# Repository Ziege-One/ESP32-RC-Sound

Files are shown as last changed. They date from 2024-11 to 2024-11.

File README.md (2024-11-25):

# ESP32-RC-Sound for RC ships or cars

ESP32-RC-Sound first based on the work done by stelatoris and XTronical 

Github stelatoris: https://github.com/stelatoris/XTronical-I2S-Audio-with-SD

Website XTronical: https://www.xtronical.com/i2sprerelease/

and XTronical Youtube: https://www.youtube.com/channel/UCOjddcYTYcZBGhpBALhX4Kg

# Info:

under docs/ESP32 RC-Sound.pdf (German only)

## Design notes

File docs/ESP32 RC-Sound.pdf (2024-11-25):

Stand 15.09.2024 12:30

# ESP32 RC-Sound

## Der RC-Modellbauer

## alias Frank Verfürth

Software 0.36

Hardware 1.0

### 1 INHALT

### 2 EINLEITUNG

- Das ESP32 RC-Sound Modul ermöglicht die Simulation von Motorsounds und kann bis zu 8 verschiedene Sounds abspielen. Diese Sounddateien werden auf einer SD-Karte gespeichert. Das Modul bietet verschiedene Ansteuerungsmethoden für den Sound bzw. Motorsound, darunter SBUS, PWM, Pin to Ground, Einkanal aus dem ESP32 SBUS-Switch sowie eine Ebenen-Umschaltung zur Kanaloptimierung. Einstellungen werden über WLAN über ein geeignetes Endgerät vorgenommen.

## 3 ESP32 RC-SOUND

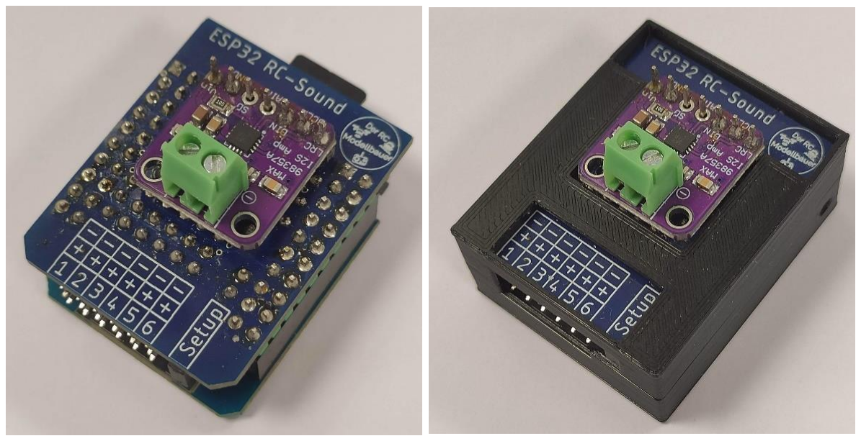
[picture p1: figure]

ESP32 RC-Sound Modul rechts ohne links mit Gehäuse aus dem 3D-Drucker

### 4 AUFBAU

### 4.1 BAUTEILE

- | ESP32 | ESP32-Mini
- Micro SD Modul
- MAX98357A I2S 3W Klasse-D-Verstärker

### 4.2 SPANNUNGSVERSORGUNG

Das Soundmodul wird über die Servostecker an Pin 1-6 mit Spannung versorgt. Die maximale Spannung beträgt 5,3V.

### 4.3 ANSCHLÜSSE

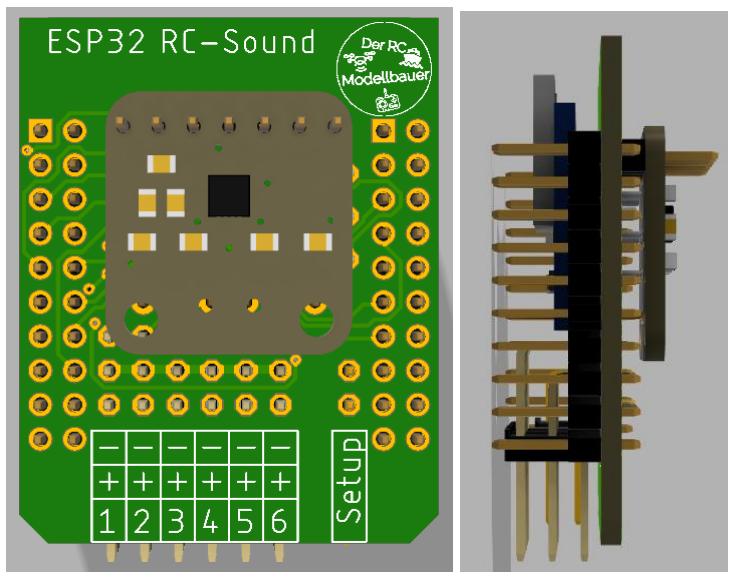
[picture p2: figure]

Pin1-6 (3Polig) sind freikonfigurierbare Eingänge siehe Verschaltung. Der „-„ Pin ist mit allen anderen „-„ Pins verbunden und mit GND der Schaltung verbunden. Die „+“ Pins sind ebenfalls alle untereinander verbunden, und dienen als Spannungsversorgung der Schaltung. Die „X“ Pins sind mit Eingängen des ESP32 verschaltet. Der Setup Pin (2Polig) dient zum aktivieren des Setupmodus und kann mit einem Jumper gesteckt werden.

### 4.3.1 SBUS

Wenn im ES32 RC-Sound Modul der SBUS verwendet werden wird dieser immer an PIN1 eingelesen.

### 4.3.2 PWM

Das PWM Signale wir je nach Einstellung am entsprechend PINx eingelesen. Ist in der Konfig „PWM PIN 2 xxx“ eingestellt wir an PIN2 ein PWM Signal eingelesen und entsprechend ausgewertet.

### 4.3.3 PIN to GND

Pin to GND ist immer nur ein Schaltbefehl. Um den entsprechend Pin zu aktivieren wird der „PINx“ mit den Pin „-„ verbunden. Dies kann über einen externen Relaiskontakt/ Mechanischer Schalter oder mit einem Negativ schaltenden Schaltmodul (ESP32 SBUS-Switch neg) erfolgen

### 5 BEDIENUNG

### 5.1 WLAN VERBINDEN

Das ESP32 RC-Sound Modul erstellt bei gesteckter Setupbrücke einen WLAN- Access Point mit folgenden Zugangsdaten

- SSID „ESP32 RC-Sound“
- Password „123456789“

Nach erfolgreicher Verbindung kann die Webseite über einen Webbrowser unter der Adresse

- http://192.168.1.1

aufgerufen werden.

## 6 SD-KARTE

### 6.1 WAVE FORMAT

- Abtastrate von 16.000 Hz ist empfehlenswert
- Mono
- Angepasste Lautstärke (Siehe Bild ca. 0,5 Amplitude)
- Software Empfehlung https://www.audacity.de/

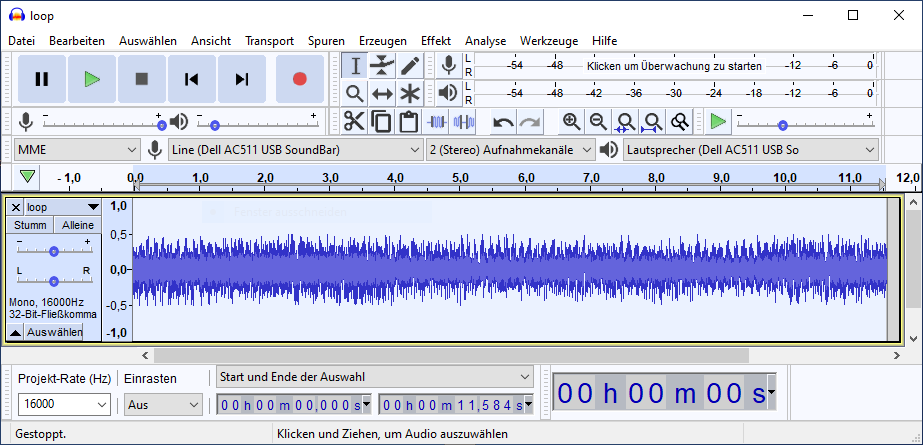
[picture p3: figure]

### 6.2 ORDNERSTRUKTUR

Die Dateien auf der SD-Karte sollten wie folgt strukturiert sein (Kleinschreibung beachten).

- | start.wav | -> | Motorstart Sound
- | loop.wav | -> | Motorgeräusch
- | shut.wav | -> | Motorabestell Sound
- | soundx.wav | -> | Sounds 1-8

### 7 WEBOBERFLÄCHE

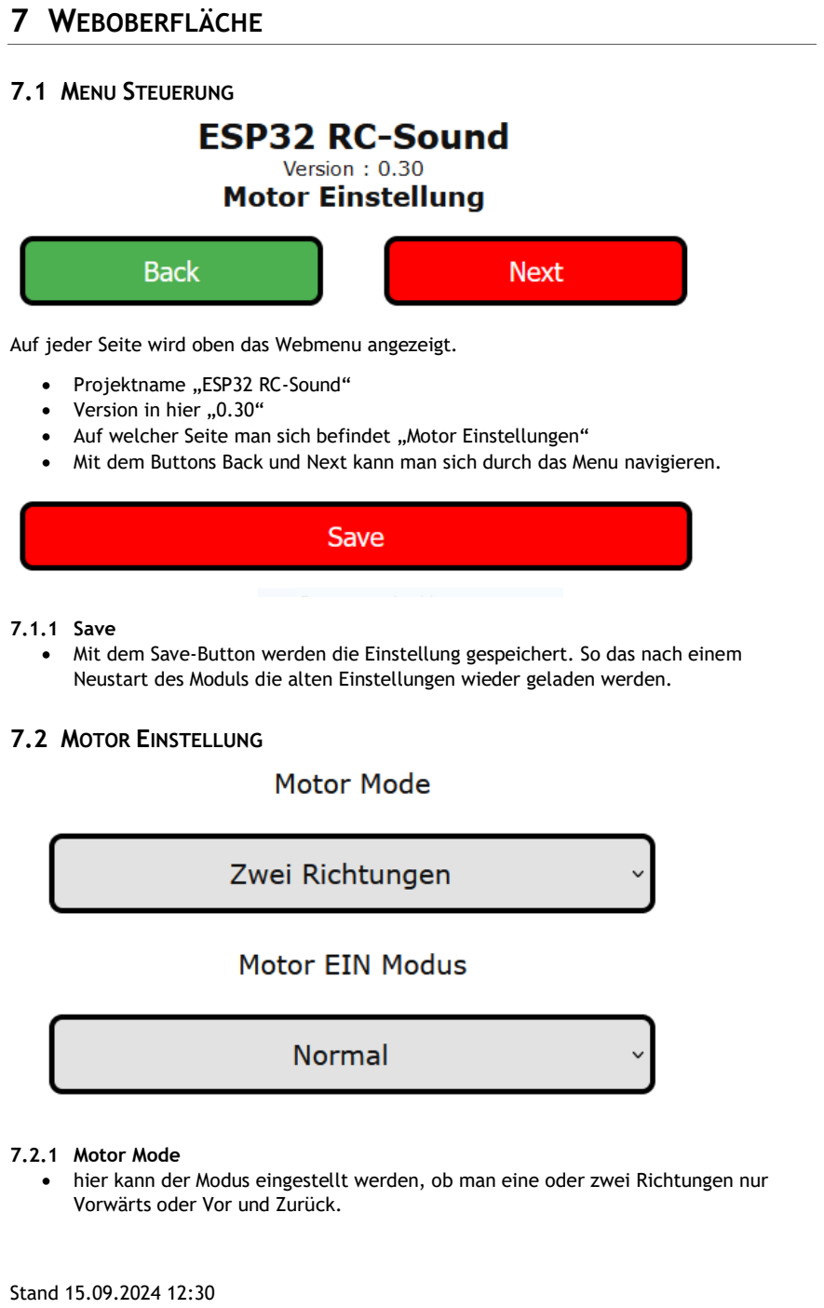
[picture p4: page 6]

### 7.1 MENU STEUERUNG

Auf jeder Seite wird oben das Webmenu angezeigt.

- Projektname „ESP32 RC-Sound“
- Version in hier „0.30“
- Auf welcher Seite man sich befindet „Motor Einstellungen“
- Mit dem Buttons Back und Next kann man sich durch das Menu navigieren.

### 7.1.1 Save

- Mit dem Save-Button werden die Einstellung gespeichert. So das nach einem Neustart des Moduls die alten Einstellungen wieder geladen werden.

### 7.2 MOTOR EINSTELLUNG

### 7.2.1 Motor Mode

- hier kann der Modus eingestellt werden, ob man eine oder zwei Richtungen nur Vorwärts oder Vor und Zurück.

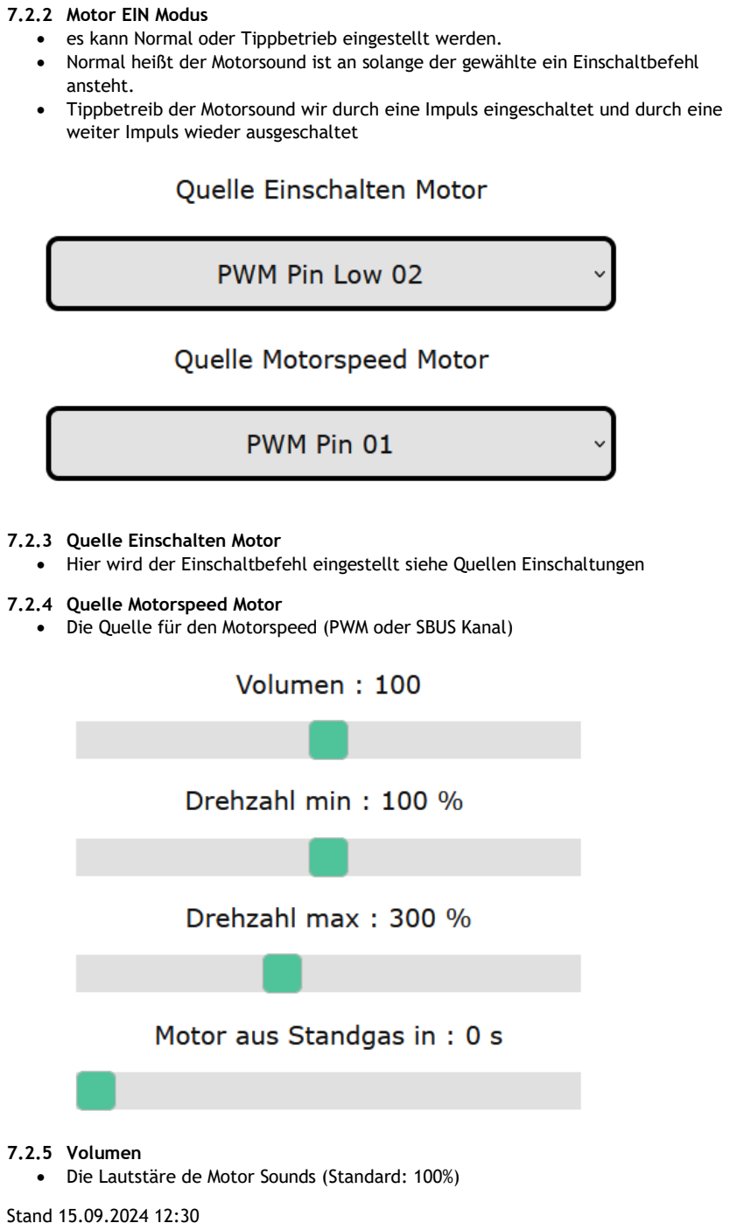
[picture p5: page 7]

### 7.2.2 Motor EIN Modus

- es kann Normal oder Tippbetrieb eingestellt werden.
- Normal heißt der Motorsound ist an solange der gewählte ein Einschaltbefehl ansteht.
- Tippbetreib der Motorsound wir durch eine Impuls eingeschaltet und durch eine weiter Impuls wieder ausgeschaltet

### 7.2.3 Quelle Einschalten Motor

- Hier wird der Einschaltbefehl eingestellt siehe Quellen Einschaltungen

### 7.2.4 Quelle Motorspeed Motor

- Die Quelle für den Motorspeed (PWM oder SBUS Kanal)

### 7.2.5 Volumen

- Die Lautstäre de Motor Sounds (Standard: 100%)

### 7.2.6 Drehzahl min

- Die Wiedergabegeschwindigkeit der loop.wav bei Standgas. 100% -> 1.0 fache Wiedergabegeschwindigkeit (Standard: 100%)

### 7.2.7 Drehzahl max

- Die Wiedergabegeschwindigkeit der loop.wav bei Vollgas. 300% -> 3.0 fache Wiedergabegeschwindigkeit (Standard: 300%)

### 7.2.8 Motor aus Standgas in

- Ist die Zeit die sich der Motor im Standgas befinden muss um automatisch abgeschaltet zu werden. 0 -> deaktiviert (Standard: 0s)

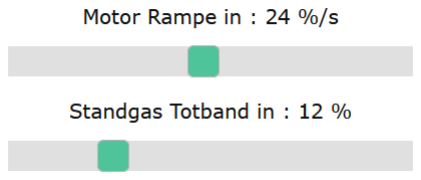
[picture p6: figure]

### 7.2.9 Motor Rampe in

- Ist die maximale Änderung der Geschwindigkeit des Motors in % pro Sekunde

### 7.2.10 Standgas Totband

- Wieviel % Gas gegeben werden muss bis der Motor aus dem Standgas kommt

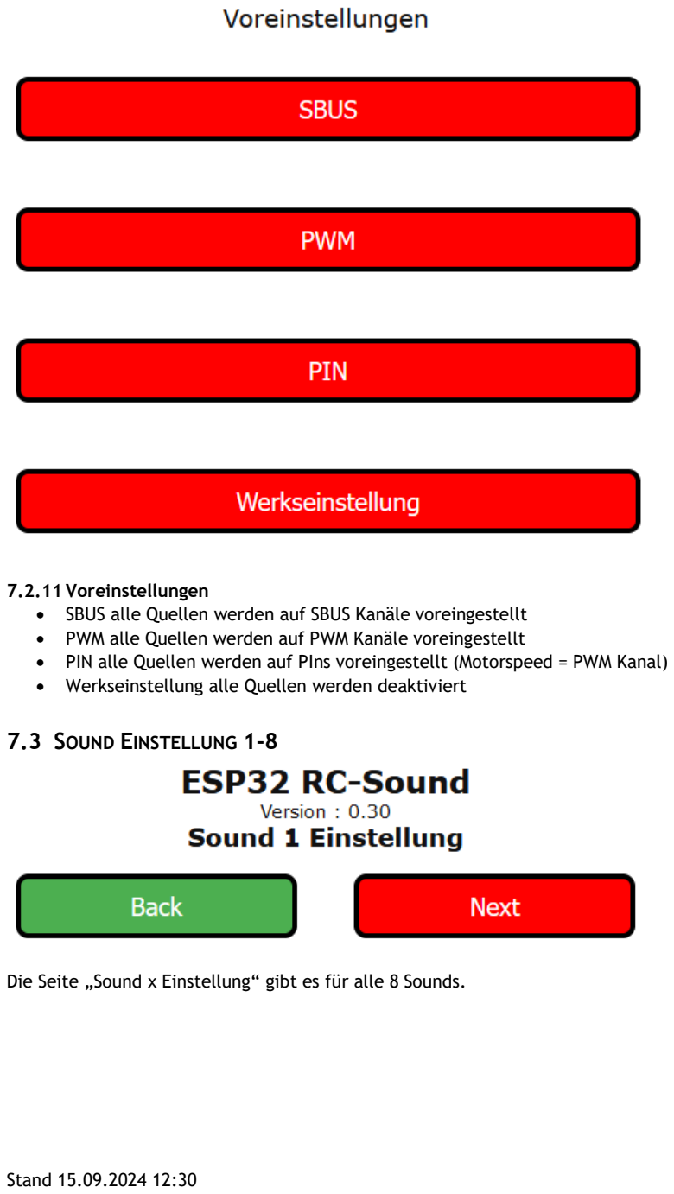
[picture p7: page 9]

### 7.2.11 Voreinstellungen

- SBUS alle Quellen werden auf SBUS Kanäle voreingestellt
- PWM alle Quellen werden auf PWM Kanäle voreingestellt
- PIN alle Quellen werden auf PIns voreingestellt (Motorspeed = PWM Kanal)
- Werkseinstellung alle Quellen werden deaktiviert

### 7.3 SOUND EINSTELLUNG 1-8

Die Seite „Sound x Einstellung“ gibt es für alle 8 Sounds.

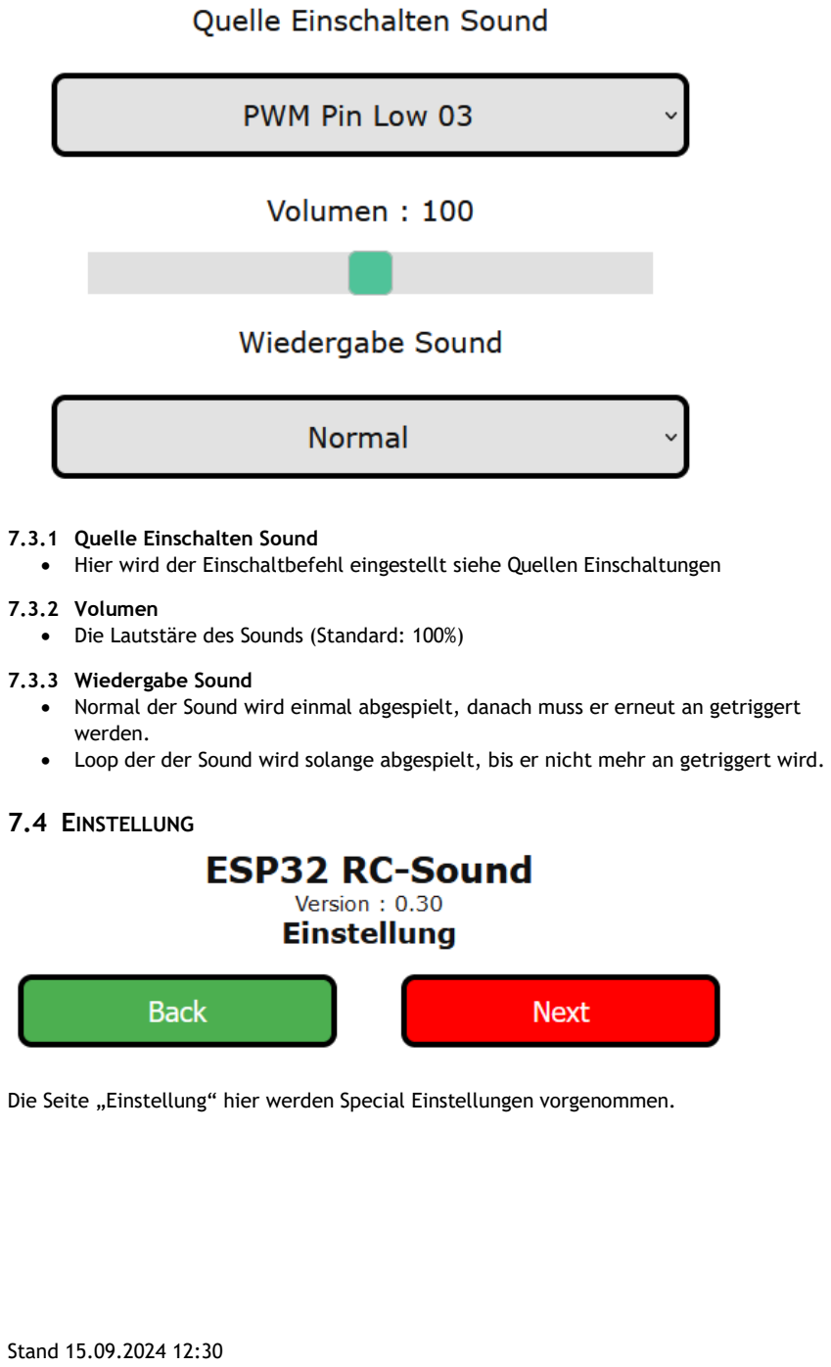
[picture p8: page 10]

### 7.3.1 Quelle Einschalten Sound

- Hier wird der Einschaltbefehl eingestellt siehe Quellen Einschaltungen

### 7.3.2 Volumen

- Die Lautstäre des Sounds (Standard: 100%)

### 7.3.3 Wiedergabe Sound

- Normal der Sound wird einmal abgespielt, danach muss er erneut an getriggert werden.
- Loop der der Sound wird solange abgespielt, bis er nicht mehr an getriggert wird.

### 7.4 EINSTELLUNG

Die Seite „Einstellung“ hier werden Special Einstellungen vorgenommen.

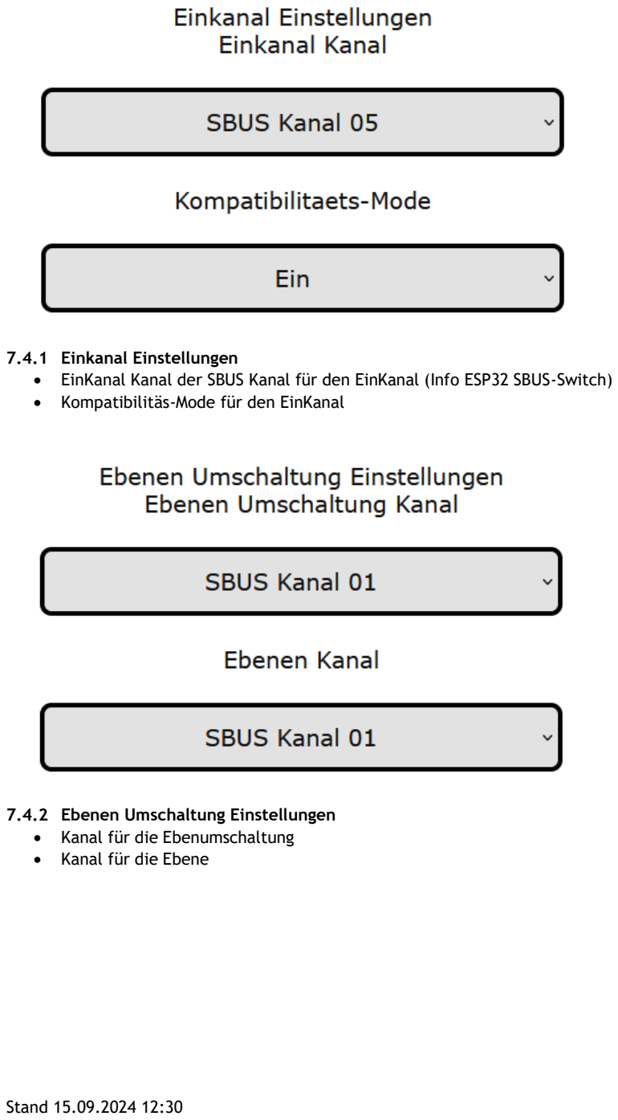
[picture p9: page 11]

### 7.4.1 Einkanal Einstellungen

- EinKanal Kanal der SBUS Kanal für den EinKanal (Info ESP32 SBUS-Switch)
- Kompatibilitäs-Mode für den EinKanal

### 7.4.2 Ebenen Umschaltung Einstellungen

- Kanal für die Ebenumschaltung
- Kanal für die Ebene

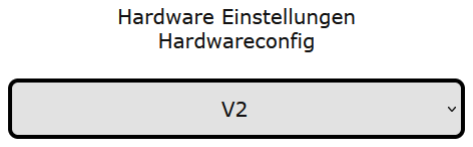
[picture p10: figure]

### 7.4.3 Hardware Einstellungen

- Hardwareconfig Platine V1 und Platine V2 siehe Anhang

### 7.5 DEBUG

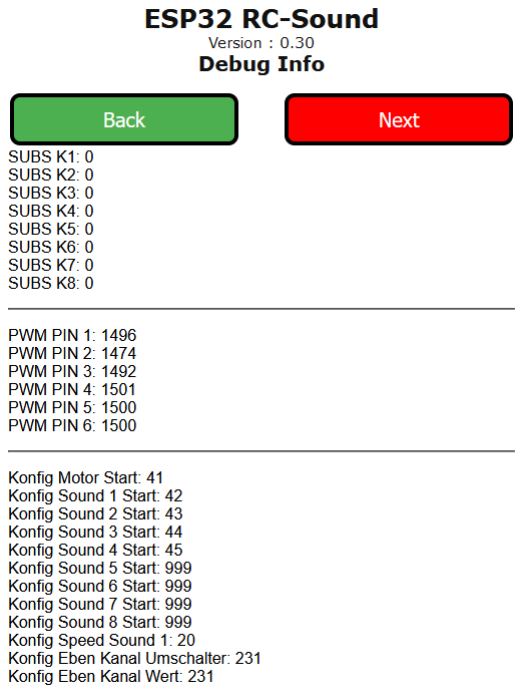
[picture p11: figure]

Hier werden Debug Informationen angezeigt

- SBUS K1-K8 die ersten 8 SBUS-Kanäle falls verwendet
- PWM PIN1-6 die PWM Werte der Pins 1-6 falls verwendet
- Anzeige der Konfig aus dem EEProm

### 8 ANHANG

### 8.1 MEHR INFORMATIONEN UND VIDEOS

- https://www.youtube.com/channel/UCkWFzuBmOhYu49MQkq89nMw

### 8.2 HARDWARE VERSIONEN

- Platine V1 Pins ESP32 1 bis 6 16; 17; 22; 0; 2; 4
- Platine V2 Pins ESP32 1 bis 6 16; 17; 14; 27; 32; 33

### 8.3 BEKANNTE PROBLEME

- Pin4 ist mit IO0 verbunden. Wenn der Pin beim Starten auf GND liegt startet der ESP32 nicht. Die ist auch bei Nutzung von PWM an diesem PIN möglich. Abhilfe erst ESP32 RC-Sound Modul mit Spannung versorgen, dann Empfänger einschalten. Die Problem wird mit ein Anderen Pin Belegung behoben.

### 8.4 SOFTWARE VERSIONSVERLAUF

- 1.0 erste Version
- 2.0 Einstellung ueber Webinterface
- 3.0 Motorstart Tippbetrieb; Motor ausschalten nach Zeit inaktive
- 3.5 8 Sounds, Im Loop abspielbar
- 3.6 Fehler von Sound 5-7 ( Konfig wurde nicht gespeichert)

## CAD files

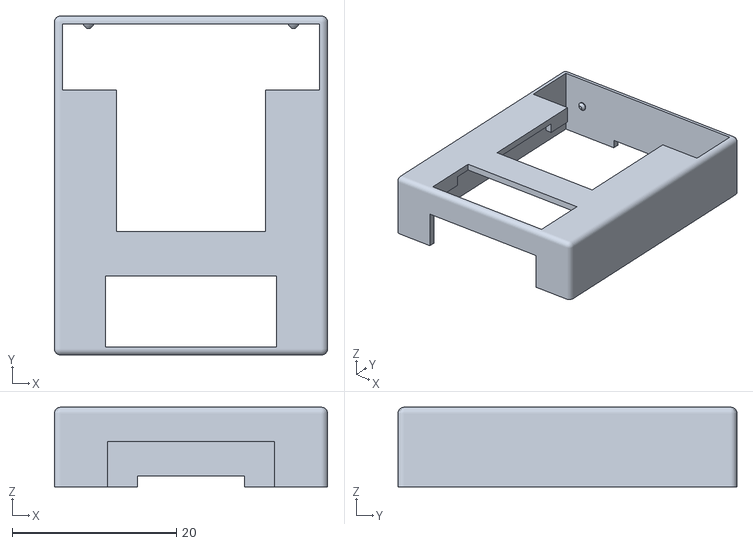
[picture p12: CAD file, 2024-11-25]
3D/Oben ESP32 RC-Sound.stl
33.3 x 41.3 x 9.70

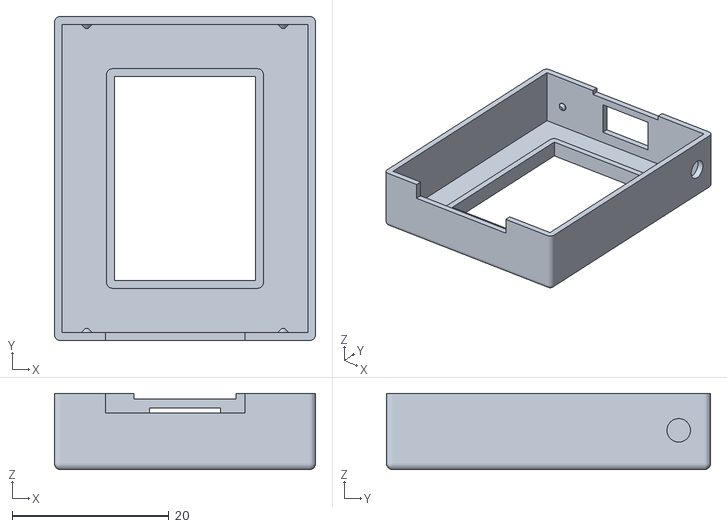
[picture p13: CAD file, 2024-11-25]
3D/Unten ESP32 RC-Sound.stl
33.3 x 41.3 x 9.70

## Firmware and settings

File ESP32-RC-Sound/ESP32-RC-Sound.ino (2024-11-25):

/*
   ESP32-RC-Sound
   Ziege-One (Der RC-Modellbauer)
 
 ESP32 + SD + S2I Audio

 /////Pin Belegung////
 GPIO 13: Wifi Pin
 GPIO 14: Hardware Pin
 GPIO 27: 
 GPIO 33: 
 GPIO 32: 
 GPIO 15: 
 GPIO 16: Input 1
 GPIO 17: Input 2
 GPIO 22: Input 3
 GPIO 00: Input 4
 GPIO 02: Input 5  
 GPIO 04: Input 6

 GPIO 05: SD_CS
 GPIO 18: SD_CLK  
 GPIO 19: SD_MISO
 GPIO 23: SD_MOSI

 GPIO 21: I2S_DOUT
 GPIO 25: I2S_LRC
 GPIO 26: I2S_BCLK

 */

// ======== ESP32-RC-Sound =======================================

/* Boardversion
ESP32                                         2.0.9
 */

/* Installierte Bibliotheken
Bolder Flight Systems SBUS                    8.1.4
 */

#include <Arduino.h>
#include "XT_I2S_Audio.h"
#include <WiFi.h>
#include <EEPROM.h>
#include "sbus.h"

const float Version = 0.36; // Software Version

// EEprom

#define EEPROM_SIZE 132

#define adr_eprom_Source_Speed_Sound_0        4   // Source_Speed_Sound 1
#define adr_eprom_Source_Start_Sound_0        8   // Source_Start_Sound 1
#define adr_eprom_Source_Start_Sound_1        12  // Source_Start_Sound 2
#define adr_eprom_Source_Start_Sound_2        16  // Source_Start_Sound 3
#define adr_eprom_Source_Start_Sound_3        20  // Source_Start_Sound 4
#define adr_eprom_Source_Start_Sound_4        24  // Source_Start_Sound 5
#define adr_eprom_Source_Start_Sound_5        28  // Source_Start_Sound 6
#define adr_eprom_Source_Start_Sound_6        32  // Source_Start_Sound 7
#define adr_eprom_Source_Start_Sound_7        36  // Source_Start_Sound 8
#define adr_eprom_Source_Start_Sound_8        40  // Source_Start_Sound 9
#define adr_eprom_Source_throttle_mode        44  // Source_Gas_Modus 1 = Vor/Zurück
#define adr_eprom_Min_Speed_Sound_0           48  // untere Geschwindigkeit Motor in % (100% ist 1fache Wiedergabegeschwindigkeit
#define adr_eprom_Max_Speed_Sound_0           52  // obere Geschwindigkeit Motor in % (150% ist 1,5fache Wiedergabegeschwindigkeit
#define adr_eprom_Volumen_Sound_0             56  // Volumen Sound 1 Normal = 100
#define adr_eprom_Volumen_Sound_1             60  // Volumen Sound 2 Normal = 100
#define adr_eprom_Volumen_Sound_2             64  // Volumen Sound 3 Normal = 100
#define adr_eprom_Volumen_Sound_3             68  // Volumen Sound 4 Normal = 100
#define adr_eprom_Volumen_Sound_4             72  // Volumen Sound 5 Normal = 100
#define adr_eprom_Volumen_Sound_5             76  // Volumen Sound 6 Normal = 100
#define adr_eprom_Volumen_Sound_6             80  // Volumen Sound 7 Normal = 100
#define adr_eprom_Volumen_Sound_7             84  // Volumen Sound 8 Normal = 100
#define adr_eprom_Volumen_Sound_8             88  // Volumen Sound 9 Normal = 100
#define adr_eprom_RepeatForever               92  // Sound Repeat (Loop)
#define adr_eprom_sbus_channel_einkanal       96  // SBUS Channel Einkanal
#define adr_eprom_sbus_channel_einkanal_mode  100  // SBUS Channel Mode Einkanal
#define adr_eprom_shutdowndelay               104  // Sekunden Gas 0 dann Motor aus
#define adr_eprom_engine_on_toogle            108  // Motor ein aus durch Toogle
#define adr_eprom_Source_Ebenen_Um_Kanal      112  // Kanal für Ebenen umschaltung
#define adr_eprom_Source_Ebenen_Kanal         116  // Kanal für Ebene
#define adr_eprom_throttle_ramp               120  // max change of throttle in one Second
#define adr_eprom_throttle_dead_band          124  // Totband Gas
#define adr_eprom_Hardware_Config             128  // Hardware Config

int Hardware_Config;                                                                            // Hardware Config
int Source_Speed_Sound_0;                                                                       // Source_Speed_Sound 1
int Min_Speed_Sound_0;                                                                          // untere Geschwindigkeit Motor in % (100% ist 1fache Wiedergabegeschwindigkeit
int Max_Speed_Sound_0;                                                                          // obere Geschwindigkeit Motor in % (150% ist 1,5fache Wiedergabegeschwindigkeit
int Source_Start_Sound[9] = {0, 0, 0, 0, 0, 0, 0, 0, 0};                                        // Source_Start_Sound 1-9
bool Source_Start_Sound_OK[9] = {false, false, false, false, false, false, false, false, false};// Source_Start_Sound 1-9 Quellen OK (SBUS oder PWM vorhanden)
int Volumen_Sound[9] = {100, 100, 100, 100, 100, 100, 100, 100, 100};                           // Lautstärke Sound 1-9

bool Sound_on[9] = {false, false, false, false, false, false, false, false, false};        // Sound starten 1-9
bool Sound_play[9] = {false, false, false, false, false, false, false, false, false};      // Sound spielt 1-9
bool Sound_on_web[9] = {false, false, false, false, false, false, false, false, false};    // Sound starten über Webinterface 1-9

bool Sound_on_Motor;       // Sound Motor starten
bool Sound_on_Motor_state; // Sound Motor Toogle Speicher

int RepeatForever = 0;     // Sound Repeat (Loop)

// EinKanalModus
int sbus_channel_einkanal = 4; // Kanal 5 default
bool sbus_channel_einkanal_mode = false;
uint16_t einkanal_Data;         // Daten für die Ausgänge

//EbenenUmschaltung
int Source_Ebenen_Um_Kanal; // 
int Source_Ebenen_Um_Kanal_wert = 0;
int Source_Ebenen_Kanal; //
int Source_Ebenen_Kanal_wert = 0;
uint16_t ebenenkanal_Data = 99;         // Daten für die Ausgänge 

// SD Card 
#define SD_CS 5 // SD Card chip select

// I2S Audio
#define I2S_DOUT 21 // i2S Data out oin
#define I2S_BCLK 26 // Bit clock
#define I2S_LRC  25 // Left/Right clock, also known as Frame clock or word select

// Pins zuweisen 
volatile unsigned char WifiPin = 13;
volatile unsigned char LedPin = 2;
volatile unsigned char Input_Pin[6]  ={16, 17, 22, 0, 2, 4}; // Pin-Eingang


// Motor
bool throttle_mode; 
bool engine_break;
bool engine_on_toogle;
int shutdowndelay = 15;               					          // Number of seconds to wait before shutdown sound is played.
unsigned long shutdown_timer;
volatile uint8_t engine_State = 0;                        // Motor Status 
enum Engine_State                                         // Motor Status enum
{
  OFF,
  STARTING,
  RUNNING,
  STOPPING,
};

// Ramp
unsigned long previousTime_ramp = 0;         // Previous time
float last_throttle = 0;
int throttle_ramp = 20;       // max change of throttle in one Second
float throttle;      
int throttle_dead_band = 10;  //Totband Gas

// Wlan Einstellungen AP Modus
const char* ssid     = "ESP32-RC-Sound";
const char* password = "123456789";

// Webserver auf Port 80
WiFiServer server(80);

// Speicher HTTP request
String header;

// Für HTTP GET value
String valueString = String(5);
int pos1 = 0;
int pos2 = 0;

int Menu = 0;

//Timer Zeiten
unsigned long currentTime = millis();   // Aktuelle Zeit
unsigned long previousTime = 0;         // Previous time
const long timeoutTime = 2000;          // Define timeout time in milliseconds (example: 2000ms = 2s)

// SBUS
bfs::SbusRx sbus_rx(&Serial2,16, 27,true); // Sbus auf Serial2

bfs::SbusData sbus_data;

bool SBUS_OK = false;

// I2S 
XT_I2S_Class I2SAudio(I2S_LRC, I2S_BCLK, I2S_DOUT, I2S_NUM_0);

// Sounds Laden 
XT_Wav_Class Sound_loop("/loop.wav");
XT_Wav_Class Sound_shut("/shut.wav");
XT_Wav_Class Sound_start("/start.wav");
XT_Wav_Class Sound1("/sound1.wav");
XT_Wav_Class Sound2("/sound2.wav");
XT_Wav_Class Sound3("/sound3.wav");
XT_Wav_Class Sound4("/sound4.wav");
XT_Wav_Class Sound5("/sound5.wav");
XT_Wav_Class Sound6("/sound6.wav");
XT_Wav_Class Sound7("/sound7.wav");
XT_Wav_Class Sound8("/sound8.wav");

// PWM lesen mit Interrupt
volatile unsigned int PWM_pulse_width[6] = {3000, 3000, 3000, 3000, 3000, 3000};  
volatile unsigned int PWM_prev_time[6] = {0, 0, 0, 0, 0, 0}; 

void PWM_UP_0() {
  attachInterrupt(digitalPinToInterrupt(Input_Pin[0]), &PWM_DOWN_0, FALLING);  // wird der PIN false, rufe PWM_DOWN_X auf
  PWM_prev_time[0] = micros();
}
 
void PWM_DOWN_0() {
  attachInterrupt(digitalPinToInterrupt(Input_Pin[0]), &PWM_UP_0, RISING);  // wird der PIN high, rufe PWM_UP_X auf
  PWM_pulse_width[0] = micros() - PWM_prev_time[0];
}

void PWM_UP_1() {
  attachInterrupt(digitalPinToInterrupt(Input_Pin[1]), &PWM_DOWN_1, FALLING);  // wird der PIN false, rufe PWM_DOWN_X auf
  PWM_prev_time[1] = micros();
}
 
void PWM_DOWN_1() {
  attachInterrupt(digitalPinToInterrupt(Input_Pin[1]), &PWM_UP_1, RISING);  // wird der PIN high, rufe PWM_UP_X auf
  PWM_pulse_width[1] = micros() - PWM_prev_time[1];
}

void PWM_UP_2() {
  attachInterrupt(digitalPinToInterrupt(Input_Pin[2]), &PWM_DOWN_2, FALLING);  // wird der PIN false, rufe PWM_DOWN_X auf
  PWM_prev_time[2] = micros();
}
 
void PWM_DOWN_2() {
  attachInterrupt(digitalPinToInterrupt(Input_Pin[2]), &PWM_UP_2, RISING);  // wird der PIN high, rufe PWM_UP_X auf
  PWM_pulse_width[2] = micros() - PWM_prev_time[2];
}

void PWM_UP_3() {
  attachInterrupt(digitalPinToInterrupt(Input_Pin[3]), &PWM_DOWN_3, FALLING);  // wird der PIN false, rufe PWM_DOWN_X auf
  PWM_prev_time[3] = micros();
}
 
void PWM_DOWN_3() {
  attachInterrupt(digitalPinToInterrupt(Input_Pin[3]), &PWM_UP_3, RISING);  // wird der PIN high, rufe PWM_UP_X auf
  PWM_pulse_width[3] = micros() - PWM_prev_time[3];
}

void PWM_UP_4() {
  attachInterrupt(digitalPinToInterrupt(Input_Pin[4]), &PWM_DOWN_4, FALLING);  // wird der PIN false, rufe PWM_DOWN_X auf
  PWM_prev_time[4] = micros();
}
 
void PWM_DOWN_4() {
  attachInterrupt(digitalPinToInterrupt(Input_Pin[4]), &PWM_UP_4, RISING);  // wird der PIN high, rufe PWM_UP_X auf
  PWM_pulse_width[4] = micros() - PWM_prev_time[4];
}

void PWM_UP_5() {
  attachInterrupt(digitalPinToInterrupt(Input_Pin[5]), &PWM_DOWN_5, FALLING);  // wird der PIN false, rufe PWM_DOWN_X auf
  PWM_prev_time[5] = micros();
}
 
void PWM_DOWN_5() {
  attachInterrupt(digitalPinToInterrupt(Input_Pin[5]), &PWM_UP_5, RISING);  // wird der PIN high, rufe PWM_UP_X auf
  PWM_pulse_width[5] = micros() - PWM_prev_time[5];
}

// ======== Setup =======================================
void setup()
{
  Serial.begin(115200); // Used for info/debug

  EEPROM.begin(EEPROM_SIZE); //Eprom init

  EEprom_Load(); // Einstellung laden
  
  sbus_rx.Begin(); // SBUS init

  // Config Modus
  if (Hardware_Config == 0)
  {
    Serial.print("Config V1");
    Input_Pin[0] = 16; // Pin-Eingang
    Input_Pin[1] = 17; // Pin-Eingang
    Input_Pin[2] = 22; // Pin-Eingang
    Input_Pin[3] =  0; // Pin-Eingang
    Input_Pin[4] =  2; // Pin-Eingang
    Input_Pin[5] =  4; // Pin-Eingang
  }
  else if (Hardware_Config == 1)
  {
    Serial.print("Config V2");
    Input_Pin[0] = 16; // Pin-Eingang
    Input_Pin[1] = 17; // Pin-Eingang
    Input_Pin[2] = 14; // Pin-Eingang
    Input_Pin[3] = 27; // Pin-Eingang
    Input_Pin[4] = 32; // Pin-Eingang
    Input_Pin[5] = 33; // Pin-Eingang 
  }

  pinMode(WifiPin, INPUT_PULLUP);
  //pinMode(LedPin, OUTPUT);

  //pinMode(Input_Pin[0], INPUT_PULLUP); 
  pinMode(Input_Pin[1], INPUT_PULLUP); 
  pinMode(Input_Pin[2], INPUT_PULLUP);    
  pinMode(Input_Pin[3], INPUT_PULLUP);    
  pinMode(Input_Pin[4], INPUT_PULLUP); 
  pinMode(Input_Pin[5], INPUT_PULLUP); 
  
  SDCardInit();
  LoadFiles();  // lade Wave Dateien

  if (!digitalRead(WifiPin)) // Setup Modus
  {
    //digitalWrite(LedPin, HIGH);  
    Serial.print("AP (Zugangspunkt) einstellen…");
    WiFi.softAP(ssid, password);

    Serial.println("IP Adresse einstellen");
    IPAddress Ip(192, 168, 1, 1);
    IPAddress NMask(255, 255, 255, 0);
    WiFi.softAPConfig(Ip, Ip, NMask);
  
    IPAddress IP = WiFi.softAPIP();
    Serial.print("AP-IP-Adresse: ");
    Serial.println(IP);
  
    server.begin();  // Start Webserver
  }
  else
  {
    Serial.println("Kein AP-Normalmodus");  
  }

}


// ======== Loop =======================================
void loop()
{
  currentTime = millis();           // Aktuelle Zeit erneuern
  
  if (!digitalRead(WifiPin))        // Setup Modus
  {     
    Webpage();                      // Webseite laden
  }
  
  if (sbus_rx.Read())               // SBUS Daten vorhanden ?
  {
    SBUS_OK = true;                 // SBUS ist vorhanden  
    sbus_data = sbus_rx.data();     // SBUS Daten lesen 

    einkanalFunction();             // Einkanal auswerten

  }

  Config();                 // Einstellungen anwenden
  
  I2SAudio.FillBuffer();

  if (!Source_Start_Sound_OK[0] or !Source_Start_Sound_OK[1] or !Source_Start_Sound_OK[2] or !Source_Start_Sound_OK[3] or !Source_Start_Sound_OK[4]) // eine Einstellung nicht OK Augabe Fehler
  {
    Serial.print("Signal OK für Sound 1: ");
    Serial.print(Source_Start_Sound_OK[0]);
    Serial.print(" 2: "); 
    Serial.print(Source_Start_Sound_OK[1]);
    Serial.print(" 3: "); 
    Serial.print(Source_Start_Sound_OK[2]);
    Serial.print(" 4: "); 
    Serial.print(Source_Start_Sound_OK[3]);
    Serial.print(" 5: "); 
    Serial.print(Source_Start_Sound_OK[4]);
  }

  if (currentTime > 5000)  //Startup warte eben 5 Sekunden
  {

    ebenenFunction();

  if (Sound_on[1] or Sound_on_web[1])    // Spiele Sound 1
  {
    if (not Sound_play[1])
    {  
      Sound_play[1] = true;
      Sound1.LoadWavFile();
      Sound1.Volume = Volumen_Sound[1];
      Sound1.RepeatForever = bitRead(RepeatForever , 1);
      I2SAudio.Play(&Sound1);
      Sound_on_web[1] = false;   
    }
  }
  else
  {
    Sound1.RepeatForever = false;
    if (not Sound1.Playing and Sound_play[1])
    {
      Sound1.UnLoadWavFile();
      Sound_play[1] = false;      
    }    
  } 
  
  if (Sound_on[2] or Sound_on_web[2])    // Spiele Sound 2
  { 
    if (not Sound_play[2])
    {      
      Sound_play[2] = true;
      Sound2.LoadWavFile();
      Sound2.Volume = Volumen_Sound[2];
      Sound2.RepeatForever = bitRead(RepeatForever , 2);
      I2SAudio.Play(&Sound2);
      Sound_on_web[2] = false;
    }    
  }
  else
  {
    Sound2.RepeatForever = false;
    if (not Sound2.Playing and Sound_play[2])
    {
      Sound2.UnLoadWavFile();
      Sound_play[2] = false;      
    }    
  } 

  if (Sound_on[3] or Sound_on_web[3])    // Spiele Sound 3
  {
    if (not Sound_play[3])
    {  
      Sound_play[3] = true;   
      Sound3.LoadWavFile();
      Sound3.Volume = Volumen_Sound[3];
      Sound3.RepeatForever = bitRead(RepeatForever , 3);
      I2SAudio.Play(&Sound3);
      Sound_on_web[3] = false;      
    }
  }
  else
  {
    Sound3.RepeatForever = false;
    if (not Sound3.Playing and Sound_play[3])
    {
      Sound3.UnLoadWavFile();
      Sound_play[3] = false;
    }    
  } 

  if (Sound_on[4] or Sound_on_web[4])    // Spiele Sound 4
  {
    if (not Sound_play[4])
    {      
      Sound_play[4] = true;  
      Sound4.LoadWavFile();
      Sound4.Volume = Volumen_Sound[4];
      Sound4.RepeatForever = bitRead(RepeatForever , 4);
      I2SAudio.Play(&Sound4);
      Sound_on_web[4] = false;      
    }
  }
  else
  {
    Sound4.RepeatForever = false;
    if (not Sound4.Playing and Sound_play[4])
    {
      Sound4.UnLoadWavFile();
      Sound_play[4] = false;
    }    
  }   

  if (Sound_on[5] or Sound_on_web[5])    // Spiele Sound 5
  {
    if (not Sound_play[5])
    {      
      Sound_play[5] = true;  
      Sound5.LoadWavFile();
      Sound5.Volume = Volumen_Sound[5];
      Sound5.RepeatForever = bitRead(RepeatForever , 5);
      I2SAudio.Play(&Sound5);
      Sound_on_web[5] = false;      
    }
  }
  else
  {
    Sound5.RepeatForever = false;
    if (not Sound5.Playing and Sound_play[5])
    {
      Sound5.UnLoadWavFile();
      Sound_play[5] = false;
    }    
  }  

  if (Sound_on[6] or Sound_on_web[6])    // Spiele Sound 6
  {
    if (not Sound_play[6])
    {      
      Sound_play[6] = true;  
      Sound6.LoadWavFile();
      Sound6.Volume = Volumen_Sound[6];
      Sound6.RepeatForever = bitRead(RepeatForever , 6);
      I2SAudio.Play(&Sound6);
      Sound_on_web[6] = false;      
    }
  }
  else
  {
    Sound6.RepeatForever = false;
    if (not Sound6.Playing and Sound_play[6])
    {
      Sound6.UnLoadWavFile();
      Sound_play[6] = false;
    }    
  }  

  if (Sound_on[7] or Sound_on_web[7])    // Spiele Sound 7
  {
    if (not Sound_play[7])
    {      
      Sound_play[7] = true;  
      Sound7.LoadWavFile();
      Sound7.Volume = Volumen_Sound[7];
      Sound7.RepeatForever = bitRead(RepeatForever , 7);
      I2SAudio.Play(&Sound7);
      Sound_on_web[7] = false;      
    }
  }
  else
  {
    Sound7.RepeatForever = false;
    if (not Sound7.Playing and Sound_play[7])
    {
      Sound7.UnLoadWavFile();
      Sound_play[7] = false;
    }    
  }  

  if (Sound_on[8] or Sound_on_web[8])    // Spiele Sound 8
  {
    if (not Sound_play[8])
    {      
      Sound_play[8] = true;  
      Sound8.LoadWavFile();
      Sound8.Volume = Volumen_Sound[8];
      Sound8.RepeatForever = bitRead(RepeatForever , 8);
      I2SAudio.Play(&Sound8);
      Sound_on_web[8] = false;      
    }
  }
  else
  {
    Sound8.RepeatForever = false;
    if (not Sound8.Playing and Sound_play[8])
    {
      Sound8.UnLoadWavFile();
      Sound_play[8] = false;
    }    
  }    


  if (Sound_on[0] == true && !Sound_on_Motor_state && engine_on_toogle) {
    Sound_on_Motor = !Sound_on_Motor; // Toogle Motor Sound On
    Sound_on_Motor_state = true; 
  }
  else if (Sound_on[0] == false && Sound_on_Motor_state && engine_on_toogle) {
    Sound_on_Motor_state = false; 
  }
  else if (!engine_on_toogle) {
    Sound_on_Motor = Sound_on[0];
  }

	  // Motor ON OFF
  if (((Sound_on_Motor or Sound_on_web[0]) and not engine_break and not Sound_play[0]) or (throttle > 0 and engine_break and not Sound_play[0]) or (throttle > 0 and Sound_play[0])) //on
  {
	  Sound_play[0] = true;
	  shutdown_timer = millis();
	}  
  if (not Sound_on_Motor and not Sound_on_web[0]) //off
	{
	   Sound_play[0] = false;
	   engine_break = false;
	}
  if ((millis() - shutdown_timer) > (shutdowndelay * 1000) && Sound_play[0] && (shutdowndelay > 0)) //off über shutdown_timer
  {
	   Sound_play[0] = false;
	   engine_break = true;
  }	  

   switch (engine_State) {       // Motor Schrittkette
    case OFF:  
      if (Sound_play[0])
      {
        Sound_start.Volume = Volumen_Sound[0];
        I2SAudio.Play(&Sound_start);
        engine_State = STARTING;
      }
      break;
    case STARTING:
      if (not Sound_start.Playing)
      {  
        throttle = 0;
        last_throttle = 0;
        Sound_loop.RepeatForever = true;
        Sound_loop.Volume = Volumen_Sound[0];
        I2SAudio.Play(&Sound_loop);
        engine_State = RUNNING;
      }  
      break;
    case RUNNING:  
      if (not Sound_play[0])
      {
        throttle = 0;
        if (last_throttle == 0)
        {
          Sound_loop.RepeatForever = false;
          I2SAudio.StopAllSounds();
          engine_State = STOPPING;
        }
      }
      break;
    case STOPPING:
      if (not Sound_loop.Playing)
      {
        Sound_loop.RepeatForever = false;
        Sound_shut.Volume = Volumen_Sound[0];
        I2SAudio.Play(&Sound_shut);
        engine_State = OFF;
      }  
      break;  
  }

  // Geschwindigkeit Rampe und Sound Anpassung
  throttle = ramp_throttle(throttle);
  Sound_loop.Speed = floatMap(throttle, 0, 100, Min_Speed_Sound_0, Max_Speed_Sound_0) / 100;
  }
}

//------------------------------------------------------------------------------------------------------------------------
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

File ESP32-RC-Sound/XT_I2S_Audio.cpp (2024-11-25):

// XTronical I2S Audio Library, currently supporting ESP32
// May work with other processors and/or I2S DAC's with or without modifications
// (c) XTronical 2018-2021, Licensed under GNU GPL 3.0 and later, under this license absolutely no warranty given
// See www.xtronical.com for documentation
// This software is currently under active development (Feb 2021) and may change and break your code with new versions
// No responsibility is taken for this. Stick with the version that works for you, if you need newer commands from later versions
// you may have to alter your original code

#include "XT_I2S_Audio.h"
#include <math.h>
#include <cstring>
#include <hardwareSerial.h>

WavHeader_Struct WavHeader;				// Used as a place to store the header data from the wav data

/**********************************************************************************************************************/
/* global functions                                                                                                   */
/**********************************************************************************************************************/

void SetVolume(int16_t *Left, int16_t *Right, int16_t Volume)
{
	// returns the sound samples adjusted for the volume passed, volume is passed as a %
	// 0 would cause silence, 50 would be half volume, 100 would be the original volume (unchanged).  Anything above
	// 100 would cause the volume to increase (i.e. gain); A negative value will leave volume alone and return
	// original values passed in

	float Vol = float(Volume) / 100;
	if (Volume < 0)
		return;
	*Left = (*Left) * Vol;
	*Right = (*Right) * Vol;
}

/**********************************************************************************************************************/
/* XT_PlayListItem_Class                                                                                              */
/**********************************************************************************************************************/

XT_PlayListItem_Class::XT_PlayListItem_Class()
{
	RepeatForever = false;
	Repeat = 0;
	RepeatIdx = 0;
}

// Despite being marked virtual and being overridden in desendents without these I get vtable error
// issues which I really don't understand, so I put these in even though never called and all is well
void XT_PlayListItem_Class::NextSample(int16_t *Left, int16_t *Right)
{
}
void XT_PlayListItem_Class::Init()
{
}

/**********************************************************************************************************************/
/* Wave class 			                                                                                              */
/**********************************************************************************************************************/
// Despite being marked virtual and being overridden in desendents without these I get vtable error
// issues which I really don't understand, so I put these in even though never called and all is well
void XT_Wave_Class::NextSample(int16_t *Left, int16_t *Right)
{
}
void XT_Wave_Class::Init(int8_t Note)
{
}

/**********************************************************************************************************************/
/* XT_WAV_Class                                                                                              		*/
/**********************************************************************************************************************/

#define DATA_CHUNK_ID 0x61746164
#define FMT_CHUNK_ID 0x20746d66
// Convert 4 byte little-endian to a long.
#define longword(bfr, ofs) (bfr[ofs + 3] << 24 | bfr[ofs + 2] << 16 | bfr[ofs + 1] << 8 | bfr[ofs + 0])

// XT_Wav_Class::XT_Wav_Class(const unsigned char *WavData)
// {
//     // create a new wav class object
// 	memcpy(&WavHeader,WavData,44);                     // Copy the header part of the wav data into our structure
// 	SampleRate=WavHeader.SampleRate;
// 	BytesPerSample=(WavHeader.BitsPerSample/8)*WavHeader.NumChannels;
// 	DataSize=WavHeader.DataSize;
//     IncreaseBy=float(SampleRate)/SAMPLES_PER_SEC;
//     PlayingTime = (1000 * DataSize) / (uint32_t)(SampleRate);
//     Data=WavData+44;
//     Speed=1.0;
// 	Volume=100;
// }

XT_Wav_Class::XT_Wav_Class(const String &name) // Load data from file on SD Card
	: FileName{name}
{
	SamplesBufferIsEmpty = true;
	// create a new wav class object

	// 	unsigned char c;
	// size_t numRead = file.read(&c, sizeof(c));
	// if (numRead != sizeof(c)) {
	//   // error, like end of file
	//   return;
	// }
	// // process c
}

//****** LATEST ADDITIONS **************************************************

bool XT_Wav_Class::ValidWavData(WavHeader_Struct *Wav)
{

	if (memcmp(Wav->RIFFSectionID, "RIFF", 4) != 0)
	{
		Serial.print("Invalid data - Not RIFF format");
		return false;
	}
	if (memcmp(Wav->RiffFormat, "WAVE", 4) != 0)
	{
		Serial.print("Invalid data - Not Wave file");
		return false;
	}
	if (memcmp(Wav->FormatSectionID, "fmt", 3) != 0)
	{
		Serial.print("Invalid data - No format section found");
		return false;
	}
	if (memcmp(Wav->DataSectionID, "data", 4) != 0)
	{
		Serial.print("Invalid data - data section not found");
		return false;
	}
	if (Wav->FormatID != 1)
	{
		Serial.print("Invalid data - format Id must be 1");
		return false;
	}
	if (Wav->FormatSize != 16)
	{
		Serial.print("Invalid data - format section size must be 16.");
		return false;
	}
	if ((Wav->NumChannels != 1) & (Wav->NumChannels != 2))
	{
		Serial.print("Invalid data - only mono or stereo permitted.");
		return false;
	}
	if (Wav->SampleRate > 48000)
	{
		Serial.print("Invalid data - Sample rate cannot be greater than 48000");
		return false;
	}
	if ((Wav->BitsPerSample != 8) & (Wav->BitsPerSample != 16))
	{
		Serial.print("Invalid data - Only 8 or 16 bits per sample permitted.");
		return false;
	}
	return true;
}

void XT_Wav_Class::PrintData(const char *Data, uint8_t NumBytes)
{
	for (uint8_t i = 0; i < NumBytes; i++)
		Serial.print(Data[i]);
	Serial.println();
}
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
